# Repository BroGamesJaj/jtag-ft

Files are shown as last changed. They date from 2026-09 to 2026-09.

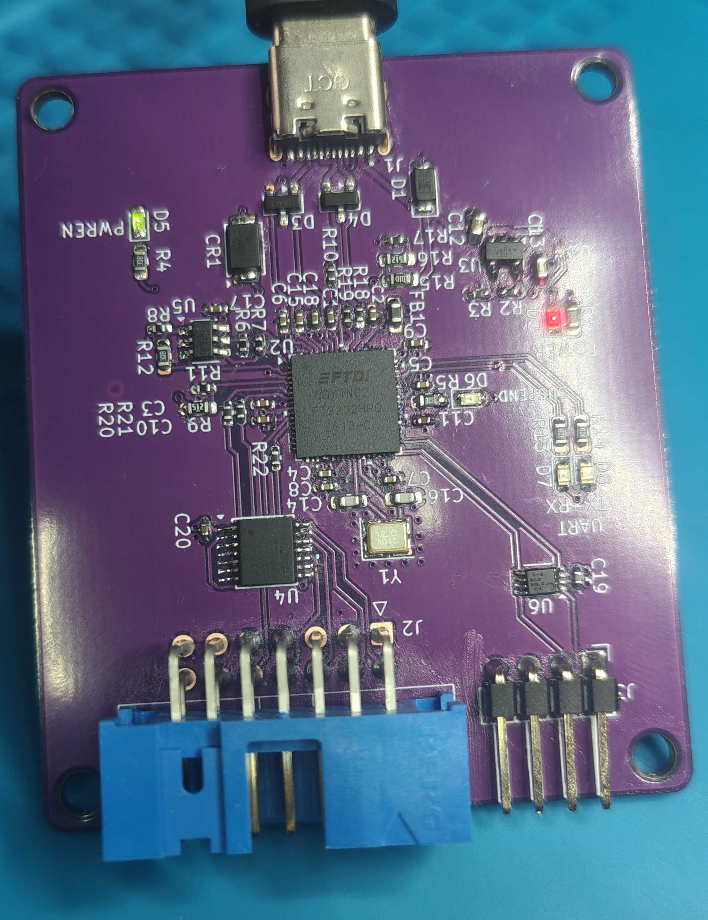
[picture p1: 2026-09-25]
images/board_image.jpg

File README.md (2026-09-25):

# JTAG-FT

A simple FT2232HP board to program and debug fpgas and other jtag capable hardware.

features:
- JTAG, 14pin xilinx jtag connector compatible
- UART
- Voltage level shifters for both UART and JTAG (1V1-5V)

setups:
- Xilinx fpga programmer:\
  download Vivado(2025.1 or newer) then use the included program_ftdi.\
  command:\
  ```program_ftdi -write -ftdi FT2232HP -serial 0ABC01 -vendor "my vendor co" -board "my board" -desc "my product desc" ```\
  After this Vivado should be able to see the board as a valid programming cable
  [official guide](https://docs.amd.com/r/en-US/ug908-vivado-programming-debugging/JTAG-Cables-and-Devices-Supported-by-hw_server)

- Lattice fpga programmer: TODO

- Altera fpga programmer: TODO

images:
assembled board

![jtag-ft board](images/board_image.jpg)

FT2232HP properties flashed

![usb device description](images/FT2232HP_programmed.png)

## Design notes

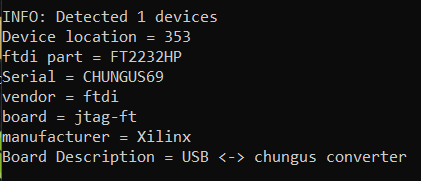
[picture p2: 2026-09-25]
images/FT2232HP_programmed.png

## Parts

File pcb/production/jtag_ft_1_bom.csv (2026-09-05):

Designator | Footprint | Quantity | Value | LCSC Part #
C1, C10, C11, C15, C17, C18, C19, C2, C20, C3, C4, C5, C6, C7, C8, C9 | 0402 | 16 | 100n
C12, C13 | 0603 | 2 | 4u7
C14, C16 | 0603 | 2 | 15p
CR1 | CFP5_SOD128_NEX | 1 | PMEG3050BEP_115
D1 | D_SMF | 1 | SMF5.0A
D2 | 0603 | 1 | RED
D3, D4 | SOT-23 | 2 | SY205215AOC
D5, D8 | 0603 | 2 | GREEN
D6, D7 | 0603 | 2 | YELLOW
FB1 | 0603 | 1 | ILBB0603ER600V
J1 | GCT_USB4930-00-A_REVA | 1 | USB4930-00-A
J2 | IDC-Header_2x07_P2.54mm_Horizontal | 1 | 75867-302LF
J3 | PinHeader_1x04_P2.54mm_Horizontal | 1 | M20-9960445
R1, R12, R13, R14, R4, R5 | 0603 | 6 | 2k
R10 | 0402 | 1 | 12k 1%
R11, R17, R6, R7, R8 | 0402 | 5 | 10k
R15 | 0603 | 1 | 100k
R16, R9 | 0603 | 2 | 5k1
R18, R19 | 0402 | 2 | 0
R2 | 0402 | 1 | 2k7
R20, R21, R22 | 0402 | 3 | 33
R3 | 0402 | 1 | 510
U1 | WLCSP4_0P64X0P64_ONS | 1 | NCP167AFCT350T2G
U2 | QFN68_FT2232_FTD | 1 | FT2232HPQ
U3 | SOT-23-5 | 1 | TLV75801PDBV
U4 | TSSOP14_PW_TEX | 1 | TXU0304PWR
U5 | SOT-23-6_MC_MCH | 1 | 93LC66BT-I/OT
U6 | SO8_DCU_TEX | 1 | TXU0202DCUR
Y1 | Crystal_SMD_Abracon_ABM8AIG-4Pin_3.2x2.5mm | 1 | ABM8-272-T3

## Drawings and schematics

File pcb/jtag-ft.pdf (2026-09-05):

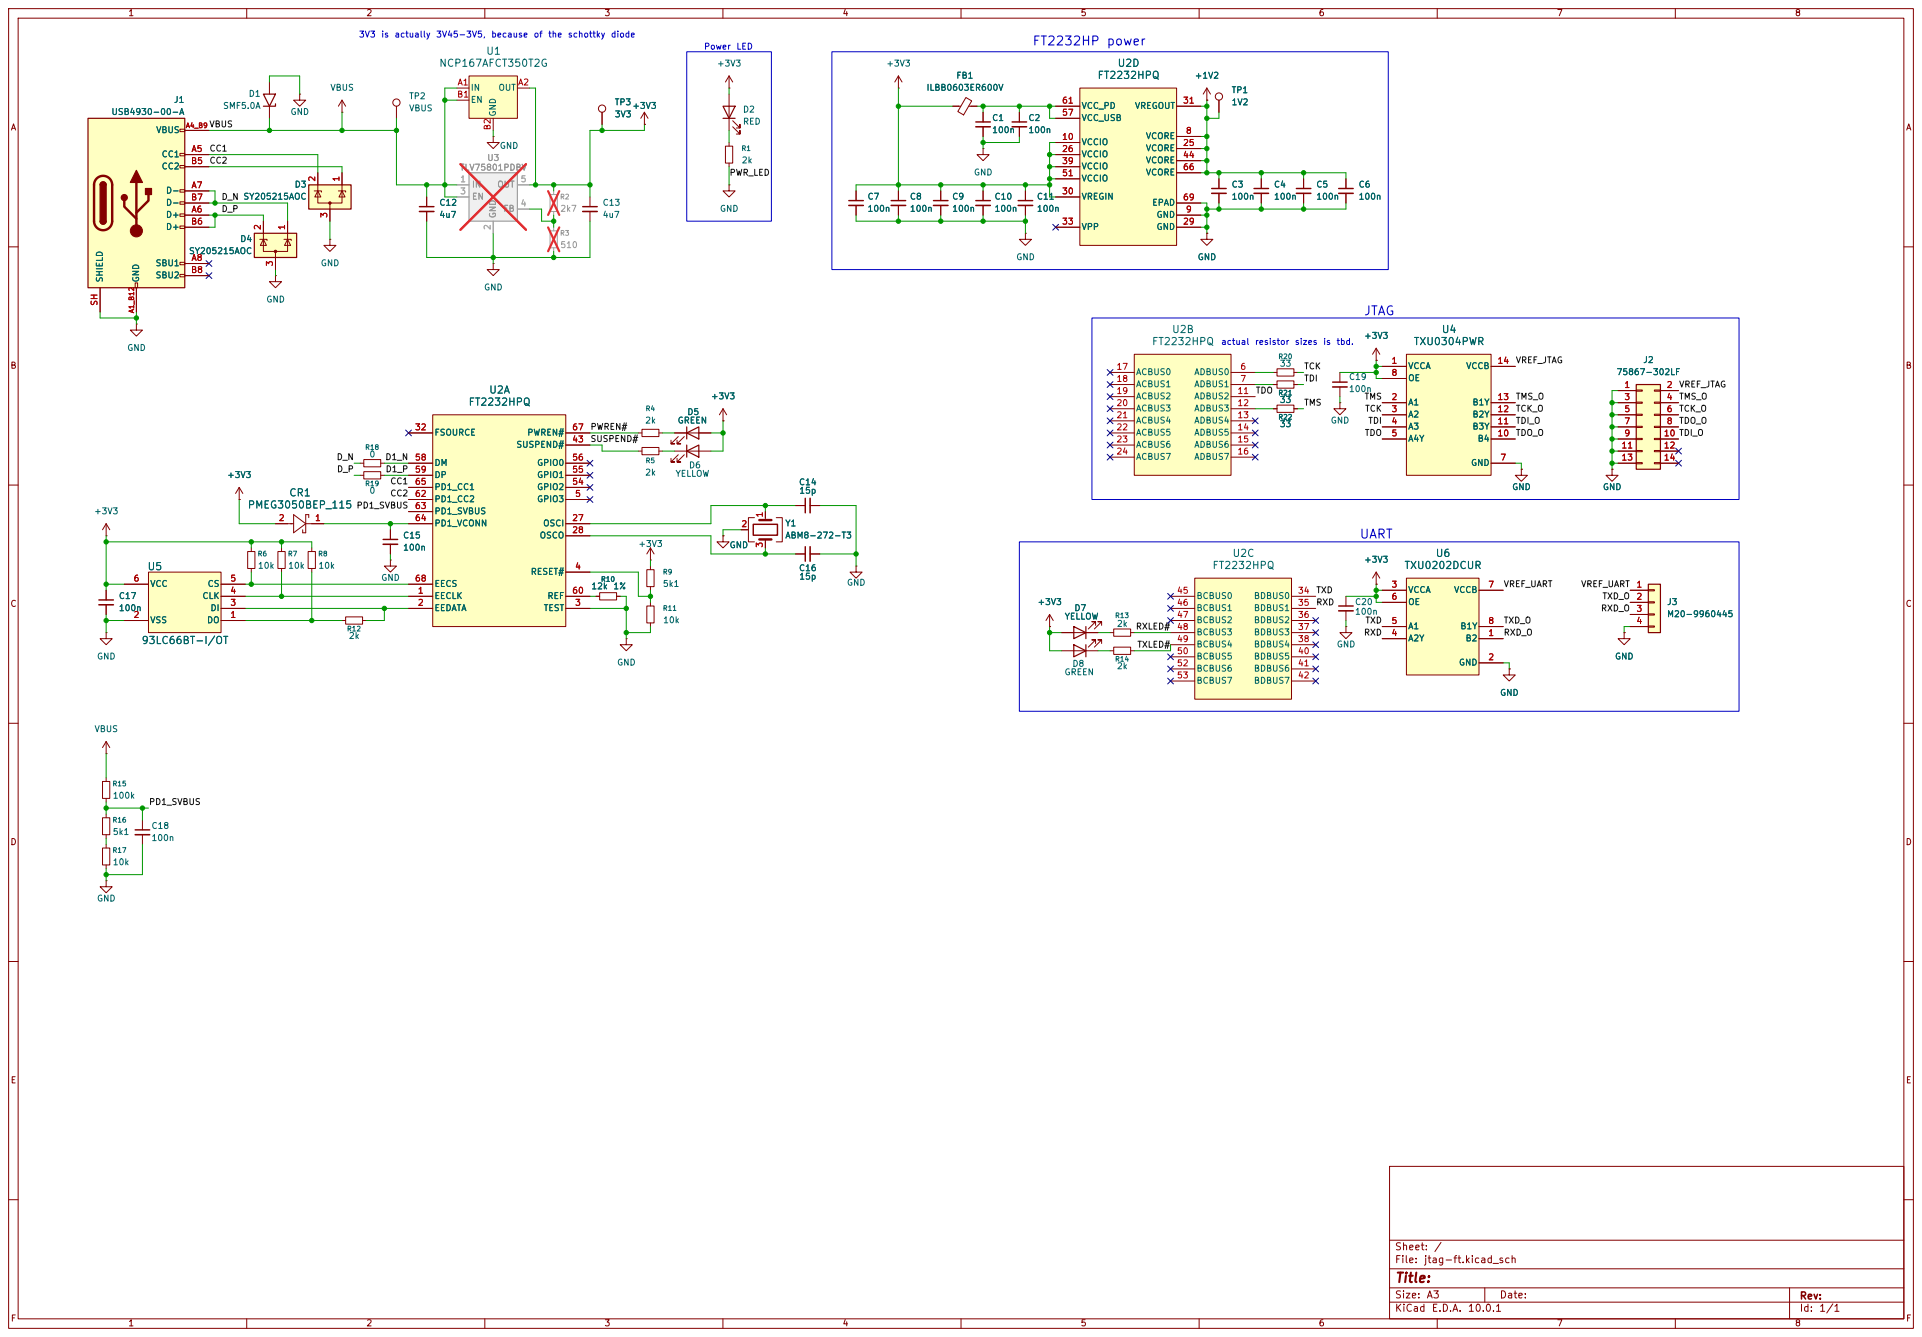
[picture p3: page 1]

Size: A3 | Rev: | F Date:
KiCad E.D.A. 10.0.1 | Id: 1/1

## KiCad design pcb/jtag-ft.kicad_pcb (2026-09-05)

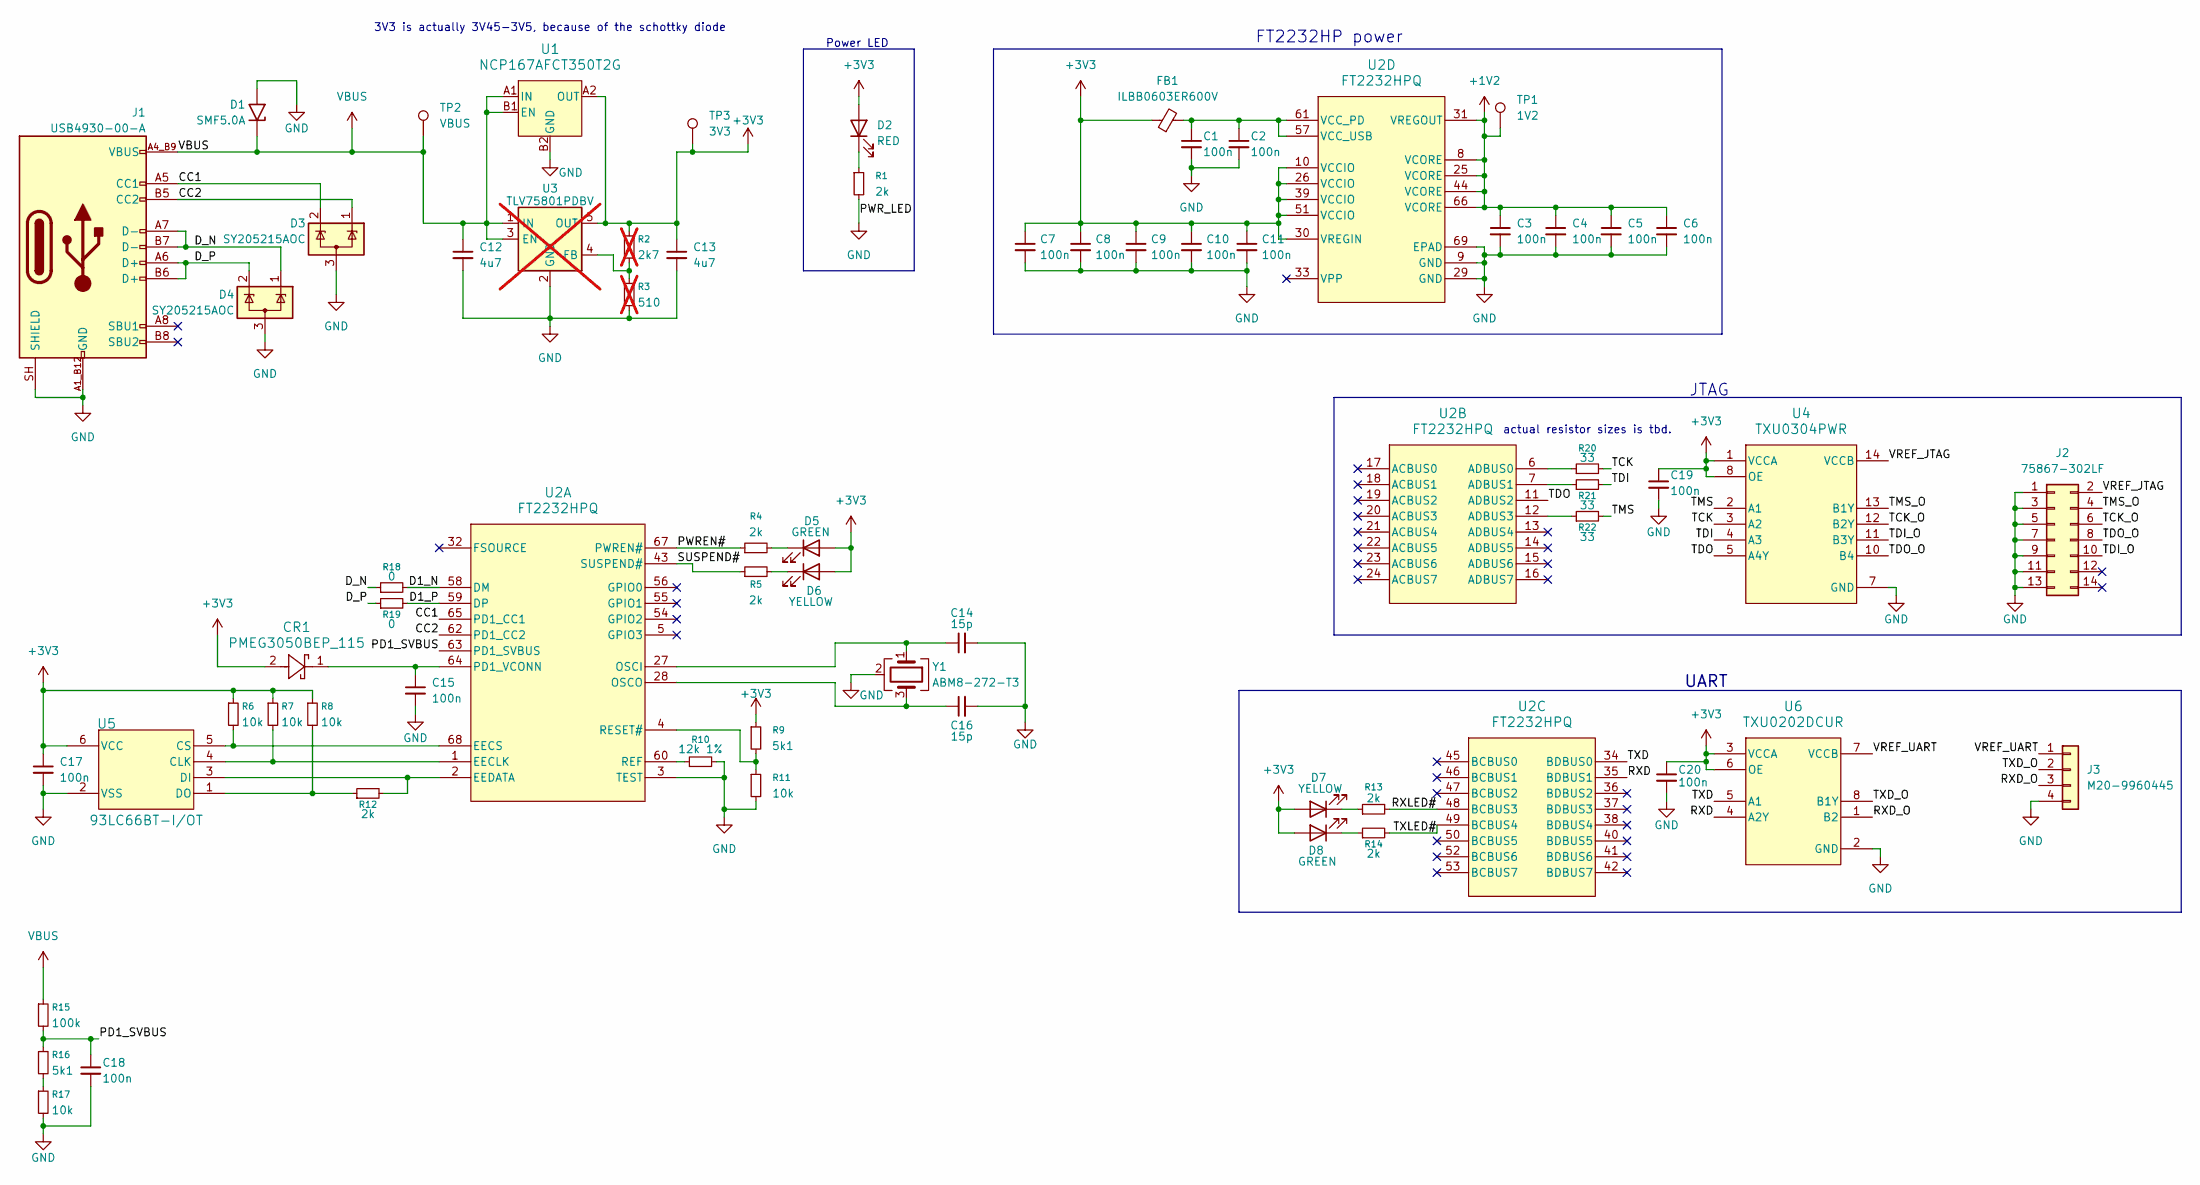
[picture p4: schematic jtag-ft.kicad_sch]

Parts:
C1, C2, C3, C4, C5, C6, C7, C8, C9, C10, C11, C15, C17, C18, C19, C20: 100n; C_0402_1005Metric_Pad0.74x0.62mm_HandSolder
C12, C13: 4u7; C_0603_1608Metric_Pad1.08x0.95mm_HandSolder
C14, C16: 15p; C_0603_1608Metric_Pad1.08x0.95mm_HandSolder
CR1: PMEG3050BEP_115; CFP5_SOD128_NEX
D1: SMF5.0A; D_SMF
D2: RED; LED_0603_1608Metric
D3, D4: SY205215AOC; SOT-23
D5, D8: GREEN; LED_0603_1608Metric
D6, D7: YELLOW; LED_0603_1608Metric
FB1: ILBB0603ER600V; R_0603_1608Metric_Pad0.98x0.95mm_HandSolder
J1: USB4930-00-A; GCT_USB4930-00-A_REVA
J2: 75867-302LF; IDC-Header_2x07_P2.54mm_Horizontal
J3: M20-9960445; PinHeader_1x04_P2.54mm_Horizontal
R1, R4, R5, R12, R13, R14: 2k; R_0603_1608Metric_Pad0.98x0.95mm_HandSolder
R2: 2k7; R_0402_1005Metric_Pad0.72x0.64mm_HandSolder; not fitted
R3: 510; R_0402_1005Metric_Pad0.72x0.64mm_HandSolder; not fitted
R6, R7, R8, R11, R17: 10k; R_0402_1005Metric_Pad0.72x0.64mm_HandSolder
R9, R16: 5k1; R_0603_1608Metric_Pad0.98x0.95mm_HandSolder
R10: 12k 1%; R_0402_1005Metric_Pad0.72x0.64mm_HandSolder
R15: 100k; R_0603_1608Metric_Pad0.98x0.95mm_HandSolder
R18, R19: 0; R_0402_1005Metric_Pad0.72x0.64mm_HandSolder
R20, R21, R22: 33; R_0402_1005Metric_Pad0.72x0.64mm_HandSolder
TP1: 1V2
TP2: VBUS
TP3: 3V3
U1: NCP167AFCT350T2G; WLCSP4_0P64X0P64_ONS
U2: FT2232HPQ; QFN68_FT2232_FTD
U3: TLV75801PDBV; SOT-23-5; not fitted
U4: TXU0304PWR; TSSOP14_PW_TEX
U5: 93LC66BT-I/OT; SOT-23-6_MC_MCH
U6: TXU0202DCUR; SO8_DCU_TEX
Y1: ABM8-272-T3; Crystal_SMD_Abracon_ABM8AIG-4Pin_3.2x2.5mm

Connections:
+1V2: C3.1, C4.1, C5.1, C6.1, TP1.1, U2.8 (VCORE), U2.25 (VCORE), U2.31 (VREGOUT), U2.44 (VCORE), U2.66 (VCORE)
+3V3: C7.1, C8.1, C9.1, C10.1, C11.1, C13.1, C17.1, C19.1, C20.1, CR1.2, D2.2 (A), D5.2 (A), D6.2 (A), D7.2 (A), D8.2 (A), FB1.1, R2.1, R6.1, R7.1, R8.1, R9.1, TP3.1, U1.A2 (OUT), U2.10 (VCCIO), U2.26 (VCCIO), U2.30 (VREGIN), U2.39 (VCCIO), U2.51 (VCCIO), U3.5 (OUT), U4.1 (VCCA), U4.8 (OE), U5.6 (VCC), U6.3 (VCCA), U6.6 (OE)
/CC1: D3.2 (K), J1.A5 (CC1), U2.65 (PD1_CC1)
/CC2: D3.1 (K), J1.B5 (CC2), U2.62 (PD1_CC2)
/D1_N: R18.2, U2.58 (DM)
/D1_P: R19.2, U2.59 (DP)
/D_N: D4.1 (K), J1.A7 (D-), J1.B7 (D-), R18.1
/D_P: D4.2 (K), J1.A6 (D+), J1.B6 (D+), R19.1
/PD1_SVBUS: C18.1, R15.2, R16.1, U2.63 (PD1_SVBUS)
/PWREN#: R4.1, U2.67 (PWREN#)
/RXD: U2.35 (BDBUS1), U6.4 (A2Y)
/RXD_O: J3.3, U6.1 (B2)
/RXLED#: R13.2, U2.48 (BCBUS3)
/SUSPEND#: R5.1, U2.43 (SUSPEND#)
/TCK: R20.2, U4.3 (A2)
/TCK_O: J2.6, U4.12 (B2Y)
/TDI: R21.2, U4.4 (A3)
/TDI_O: J2.10, U4.11 (B3Y)
/TDO: U2.11 (ADBUS2), U4.5 (A4Y)
/TDO_O: J2.8, U4.10 (B4)
/TMS: R22.2, U4.2 (A1)
/TMS_O: J2.4, U4.13 (B1Y)
/TXD: U2.34 (BDBUS0), U6.5 (A1)
/TXD_O: J3.2, U6.8 (B1Y)
/TXLED#: R14.2, U2.49 (BCBUS4)
/VREF_JTAG: J2.2, U4.14 (VCCB)
/VREF_UART: J3.1, U6.7 (VCCB)
GND: C1.2, C2.2, C3.2, C4.2, C5.2, C6.2, C7.2, C8.2, C9.2, C10.2, C11.2, C12.2, C13.2, C14.2, C15.2, C16.2, C17.2, C18.2, C19.2, C20.2, D1.2 (A2), D3.3 (A), D4.3 (A), J1.A1_B12 (GND), J1.B1_A12 (GND), J1.SH (SHIELD), J2.1, J2.3, J2.5, J2.7, J2.9, J2.11, J2.13, J3.4, R1.2, R3.2, R10.2, R11.2, R17.2, U1.B2 (GND), U2.3 (TEST), U2.9 (GND), U2.29 (GND), U2.69 (EPAD), U3.2 (GND), U4.6 (NC), U4.7 (GND), U4.9 (NC), U5.2 (VSS), U6.2 (GND), Y1.2 (G), Y1.4 (G)
unnamed: D2.1 (K), R1.1
unnamed: D5.1 (K), R4.2
unnamed: D6.1 (K), R5.2
unnamed: D7.1 (K), R13.1
unnamed: D8.1 (K), R14.1
unnamed: R16.2, R17.1
unnamed: R7.2, U2.1 (EECLK), U5.4 (CLK)
unnamed: R6.2, U2.68 (EECS), U5.5 (CS)
unnamed: R12.2, U2.2 (EEDATA), U5.3 (DI)
unnamed: C14.1, U2.27 (OSCI), Y1.1
unnamed: C16.1, U2.28 (OSCO), Y1.3
unnamed: C15.1, CR1.1, U2.64 (PD1_VCONN)
unnamed: R10.1, U2.60 (REF)
unnamed: R9.2, R11.1, U2.4 (RESET#)
unnamed: R20.1, U2.6 (ADBUS0)
unnamed: R21.1, U2.7 (ADBUS1)
unnamed: R22.1, U2.12 (ADBUS3)
unnamed: C1.1, C2.1, FB1.2, U2.57 (VCC_USB), U2.61 (VCC_PD)
unnamed: R2.2, R3.1, U3.4 (FB)
unnamed: R8.2, R12.1, U5.1 (DO)
VBUS: C12.1, D1.1 (A1), J1.A4_B9 (VBUS), J1.B4_A9 (VBUS), R15.1, TP2.1, U1.A1 (IN), U1.B1 (EN), U3.1 (IN), U3.3 (EN)

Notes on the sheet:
FT2232HP power
JTAG
actual resistor sizes is tbd.
3V3 is actually 3V45-3V5, because of the schottky diode
UART
Power LED

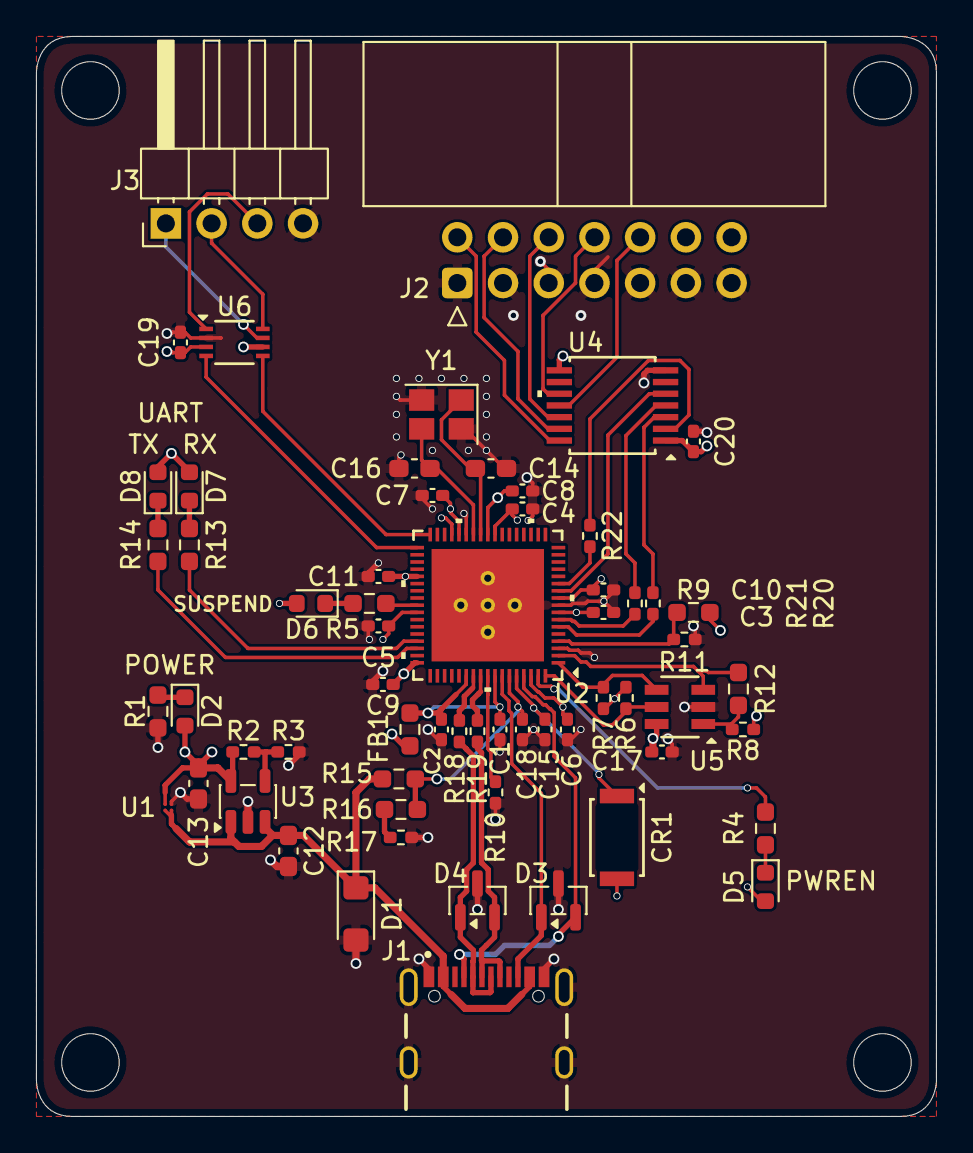
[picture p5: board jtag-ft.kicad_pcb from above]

Board: 4 copper layers, 50.0 x 60.0 mm, 62 parts (0 on the bottom side), 49 nets.

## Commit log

2026-09-05 pcb done
    [jtag-ft.kicad_pcb, jtag-ft.kicad_sch, jtag_ft_1_bom.csv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]
2026-09-05 schematic pdf
2026-09-25 Add images to README for board and device description
